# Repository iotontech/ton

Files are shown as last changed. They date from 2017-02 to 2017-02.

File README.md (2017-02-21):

Ton V1.2
========

The Ton V1.2 Board is a development and prototyping platform with Bluetooth Low Energy, Wi-Fi and IMU 9-axis,
based on the ARM Cortex-M4 32-bit microcontroller [STM32F405](http://www.st.com/web/en/catalog/mmc/SC1169/SS1577/LN1035/PF252144) developed by Brazilian startup [IOTON Technology](http://ioton.cc/).

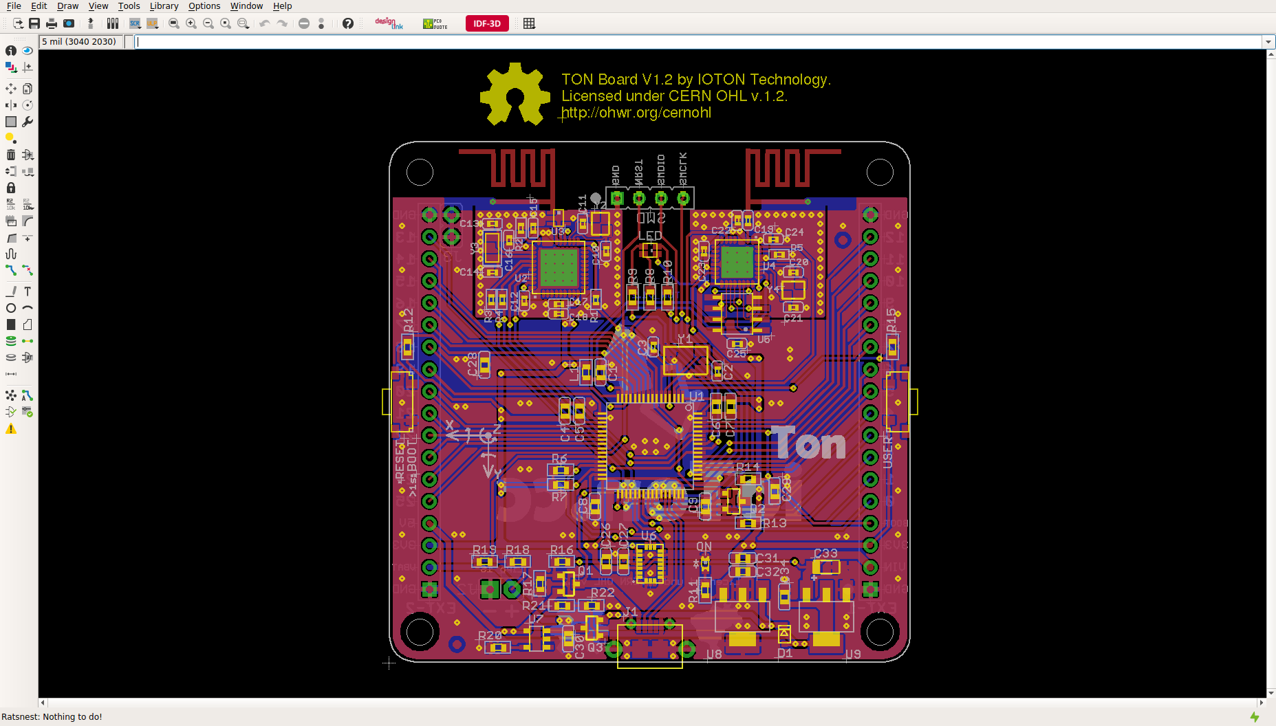
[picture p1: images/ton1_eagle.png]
ton1_eagle


# License

Copyright IOTON Technology 2017.

This documentation describes Open Hardware and is licensed under the CERN OHL v. 1.2.
You may redistribute and modify this documentation under the terms of the CERN OHL v.1.2. (http://ohwr.org/cernohl). This documentation is distributed WITHOUT ANY EXPRESS OR IMPLIED WARRANTY, INCLUDING OF MERCHANTABILITY, SATISFACTORY QUALITY AND FITNESS FOR A PARTICULAR PURPOSE. Please see the CERN OHL v.1.2 for applicable conditions.

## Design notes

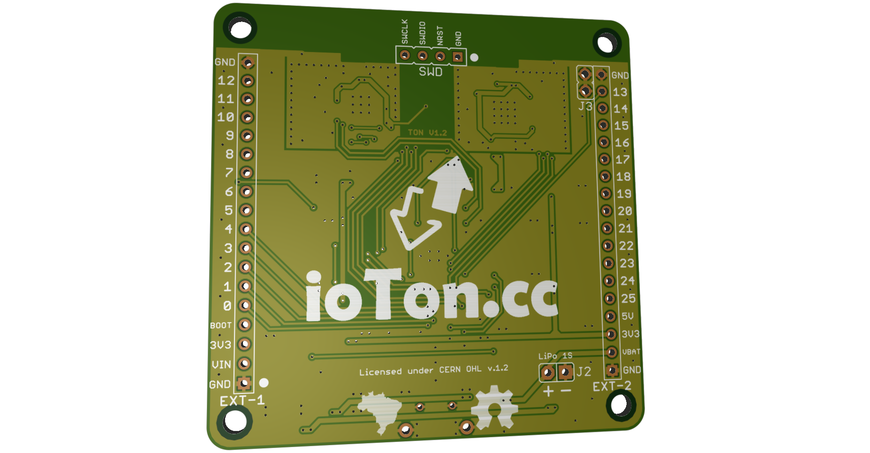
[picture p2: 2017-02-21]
images/ton1_bottom.png

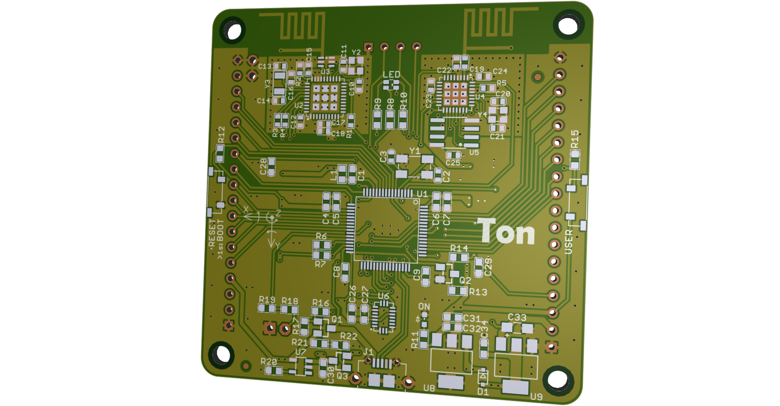
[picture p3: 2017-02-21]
images/ton1_top.png

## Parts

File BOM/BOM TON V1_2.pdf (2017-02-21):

Idn | Reference Designator | Item Type | Item Package | Item Desc | Qty | MFG Name | MFG P/N | Notes
1 | TON V1.2 | PCB | - | PCB, FR4, 1.6MM, BLUE SOLDERMASK, HASL, WHITE SILKSCREEN | 1 | | | TON_GERBERS_V1-2.ZIP
2 | C1, C5, C6, C26, C28, C31 | CERAMIC-CAP | 0603 | CAP CER 0.1UF 16V X7R 0603 10% | 6 | YAGEO | CC0603KRX7R7BB104
3 | C2, C3, C10, C11, C13, C14, C20, C21 | CERAMIC-CAP | 0402 | CAP CER 12PF 50V NP0 0402 5% | 8 | YAGEO | CC0402JRNPO9BN120
4 | C8, C9, C29 | CERAMIC-CAP | 0603 | CAP CER 2.2UF 6.3V X5R 0603 10% | 3 | YAGEO | CC0603KRX5R5BB225
5 | C4, C7, C27, C30, C32, C34 | CERAMIC-CAP | 0603 | CAP CER 1UF 6.3V X5R 0603 10% | 6 | YAGEO | CC0603KRX5R5BB105
6 | C12, C18, C25 | CERAMIC-CAP | 0402 | CAP CER 1UF 6.3V X5R 0402 10% | 3 | YAGEO | CC0402KRX5R5BB105
7 | C15, C17, C22, C24 | CERAMIC-CAP | 0402 | CAP CER 0.1UF 10V X5R 0402 10% | 4 | YAGEO | CC0402KRX5R6BB104
9 | C16, C23 | CERAMIC-CAP | 0402 | CAP CER 220PF 50V NP0 0402 5% | 2 | MURATA | GRM1555C1H221JA01
10 | C19 | CERAMIC-CAP | 0402 | CAP CER 5.6PF 50V NP0 0402 | 1 | MURATA | GRM1555C1H5R6CA01
11 | C33 | TANTALUM-CAP | 1206 | CAP TANT 10UF 1206 16V 10% | 1 | KEMET | T491A106K016AT
12 | D1 | DIODE | SOD-323 | DIODE SCHOTTKY 3.0A BAT60JFILM | 1 | STMICROELECTRONICS | BAT60JFILM
13 | EXT-1, EXT2 | HEADER-CONN | PTH-18 | CONNECTOR HEADER, FEMALE, 1X18, 2.54 PITCH | 2 | SULLINS CONNECTOR SOLUTIONS | PPTC181LFBN-RC
| | | | | | HARWIN | M20-7821842
14 | J1 | USB-CONN | SMD-5 | CONNECTOR USB MICRO AB RECEPTACLE | 1 | MOLEX | 47589-0001
15 | J2 | CONNECTOR | - | NOT PLACED | 0 | - | - | NOT PLACED
16 | J3 | HEADER-CONN | PTH-2 | CONNECTOR HEADER, MALE, 1X2, 2.54MM PITCH | 1 | 3M | 961102-6404-AR | CAN BE USED SINGLE ROW MALE 2.54MM BREAKABLE PIN HEADER CONNECTOR COMMON
| | | | | | FCI | 77311-818-02LF
17 | L1 | FERRITE-CHIP | 0603 | FERRITE CHIP 120 OHM 500MA 0603 | 1 | MURATA | BLM18AG121SN1D
| | | | | | TAIYO YUDEN | BK1608HS121-T
18 | LED | LED-RGB | 0606 | LED RGB 0606 | 1 | LITE-ON | LTST-C19HE1WT
19 | ON | LED | 0603 | LED GREEN 0603 | 1 | LITE-ON | LTST-C191KGKT
20 | Q1, Q3 | MOSFET | SSOT-3 | MOSFET FDN340P P-CHANNEL 20V 2A | 2 | FAIRCHILD SEMICONDUCTOR | FDN340P
21 | Q2 | MOSFET | SOT-23-3 | MOSFET BSS123 N-CHANNEL | 1 | FAIRCHILD SEMICONDUCTOR | BSS123
22 | R1, R3, R4 | RESISTOR-DISCRETE | 0402 | RES 0402 100 OHM 5% 1/16W | 3 | YAGEO | RC0402JR-07100RL
23 | R2 | RESISTOR-DISCRETE | 0402 | RES 0402 56.0K OHM 1% 1/16W | 1 | YAGEO | RC0402FR-0756KL
24 | R5 | RESISTOR-DISCRETE | 0402 | RES 0402 12.0K OHM 1% 1/16W | 1 | YAGEO | RC0402FR-0712KL
25 | R6, R7, R20 | RESISTOR-DISCRETE | 0603 | RES 0603 3.3K OHM 5% 1/10W | 3 | YAGEO | RC0603JR-073K3L
26 | R8, R11 | RESISTOR-DISCRETE | 0603 | RES 0603 200 OHM 5% 1/10W | 2 | YAGEO | RC0603JR-07200RL
27 | R9, R10 | RESISTOR-DISCRETE | 0603 | RES 0603 100 OHM 5% 1/10W | 2 | YAGEO | RC0603JR-07100RL
28 | R12, R14, R15, R19 | RESISTOR-DISCRETE | 0603 | RES 0603 47K OHM 5% 1/10W | 4 | YAGEO | RC0603JR-0747KL
29 | R13 | RESISTOR-DISCRETE | 0603 | RES 0603 470K OHM 5% 1/10W | 1 | YAGEO | RC0603JR-07470KL
30 | R16, R17, R21, R22 | RESISTOR-DISCRETE | 0603 | RES 0603 100K OHM 5% 1/10W | 4 | YAGEO | RC0603JR-07100KL
31 | R18 | RESISTOR-DISCRETE | 0603 | RES 0603 22K OHM 5% 1/10W | 1 | YAGEO | RC0603JR-0722KL
32 | RESET, USER | TACTILE-SWITCH | SMD-4 | TACTILE SWITCH SPST-NO RIGHT ANGLE | 2 | E-SWITCH | TL3330AF130QG
33 | SWD | CONNECTOR | - | NOT PLACED | 0 | - | - | NOT PLACED
34 | U1 | IC | LQFP-64 | IC MCU STM32F405RGT6 | 1 | STMICROELECTRONICS | STM32F405RGT6
35 | U2 | IC | VFQFN-40 | IC BLUETOOTH CC2541F256 | 1 | TEXAS INTRUMENTS | CC2541F256RHA
36 | U3 | MISCELLANEOUS | 0805 | MATCHED BALUN 2.45 GHZ | 1 | JOHANSON TECHNOLOGY | 2450BM15A0002
37 | U4 | IC | QFN-32 | IC WI-FI ESP8266EX | 1 | ESPRESSIF | ESP8266EX
38 | U5 | IC | SOIC-8 | IC FLASH 16MBIT QUAD SPI | 1 | WINBOND ELECTRONICS | W25Q16DVSNIG
39 | U6 | IC | LGA-20 | IC IMU 9-AXIS BMX055 | 1 | BOSCH SENSORTEC | BMX055
40 | U7 | IC | SOT-23-5 | IC CONTROLLER LI-ION MCP73831 | 1 | MICROCHIP TECHNOLOGY | MCP73831T-2ACI/OT
41 | U8 | IC | SOT-223-3 | IC LDO VOLTAGE REGULATOR 3.3V | 1 | DIODES INCORPORATED | AP7361C-33E-13
42 | U9 | IC | SOT-223-3 | IC LDO VOLTAGE REGULATOR 5.0V | 1 | DIODES INCORPORATED | AZ1117EH-5.0
43 | Y1 | CRYSTAL | SMD-4 | CRYSTAL ABM3B 8 MHZ | 1 | ABRACON | ABM3B-8.000MHZ-10-1UT
44 | Y2 | CRYSTAL | SMD-4 | CRYSTAL FA-20H 32 MHZ | 1 | EPSON | FA-20H 32.0000MF20X-K3
45 | Y3 | CRYSTAL | SMD-2 | CRYSTAL 32.768 KHZ | 1 | ECS | ECS-.327-12.5-34B-TR
46 | Y4 | CRYSTAL | SMD-4 | CRYSTAL FA-20H 26 MHZ | 1 | EPSON | FA-20H 26.0000MF10Z-AC3

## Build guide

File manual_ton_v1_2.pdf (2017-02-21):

Manual – Ton V1.2

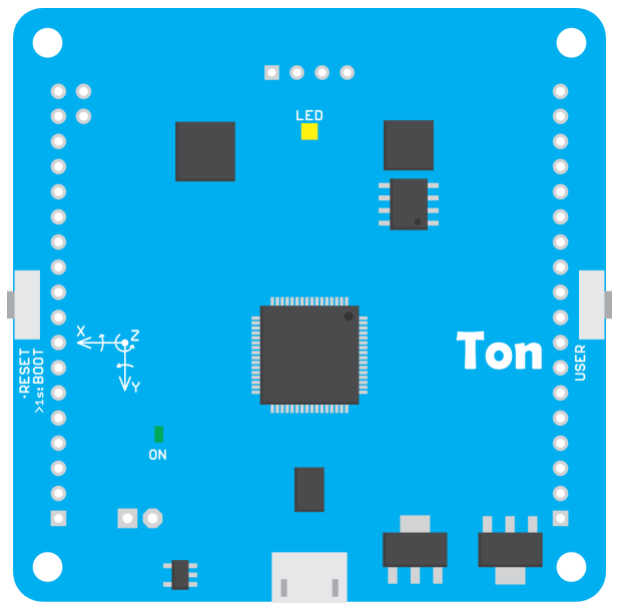
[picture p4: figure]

IOTON TECHNOLOGY – Uberlândia, abril de 2016
Site: ioton.cc (http://ioton.cc/?utm_source=google&utm_medium=referral&utm_campaign=documentacao) | E-mail: contato@ioton.cc

# TON V1.2

IOTON TECHNOLOGY | 1

# 1. Visão Geral

Ton é uma plataforma de desenvolvimento e prototipação baseada no microcontrolador ARM Cortex-M4 32-bit STM32F405. (http://www.st.com/web/en/catalog/mmc/SC1169/SS1577/LN1035/PF252144) Ele já integra uma unidade de medição inercial com 9 eixos, USB host/device, Bluetooth e Wi-Fi para você implementar suas ideias em eletrônica, robótica e IoT de uma forma simples, porém muito poderosa com um processador de 210 DMIPS (210 milhões de instruções por segundo). São 26 pinos de entradas/saídas, sendo até 12 saídas PWM e até 12 entradas analógicas. Pode ser alimentado pelo conector USB, pelo conector header ou ainda por bateria de uma célula de Li-Po (com carregador integrado). O seu header principal também permite a conexão com os seguintes periféricos: 4 UART, 2 saídas DAC, 1 i²C, 1 SPI e 1 SDIO.

A programação do Ton é realizada a partir do editor de texto Atom (https://atom.io/) e do package da IOTON que permite a utilização de todos estes recursos com uma abordagem bem prática e intuitiva. Na etapa inicial de criação do projeto, o usuário define as funções dos pinos de entradas/saídas, com isso, é gerado automaticamente todas as configurações e funções de acesso para os respectivos periféricos. Mesmo com poucas noções de programação é possível aproveitar todos os recursos do Ton devido à abstração de alto nível da API desenvolvida em linguagem C/C++ e com o uso de bibliotecas do mbed SDK. (https://github.com/mbedmicro/mbed)

IOTON TECHNOLOGY | 2

# 2. Especificações Técnicas

Microcontrolador | STM32F405RGT6
Memória Flash | 1024 KB
SRAM | 192 KB
Clock | 168 MHz (210 DMIPS)
Tensão de operação | 3,3 V (1)
Tensão de entrada (VIN) | 6 a 12 V
Corrente DC por pino | 8 mA
Corrente DC dos pinos 3V3 e 5V | 500 mA
Corrente DC do carregador Lipo 1S | 300 mA
Bluetooth Low Energy | CC2541
Botões | Reset e Usuário
IMU 9DOF | BMX055
LEDs de usuário | RGB (com PWM)
USB 2.0 full-speed | Host/device
Wi-Fi | ESP8266
Total de pinos I/O | 26 (todos com interrupção)
Saídas PWM | até 12
Entradas analógicas 12-bit | até 12
UART | 4
Saídas DAC 12-bit | 2
I²C | 1
SPI | 1
SDIO (sd card) | 1
Dimensões | 60x60x13mm
1. Os pinos de I/O são 5 V tolerantes, exceto os pinos 20 e 21

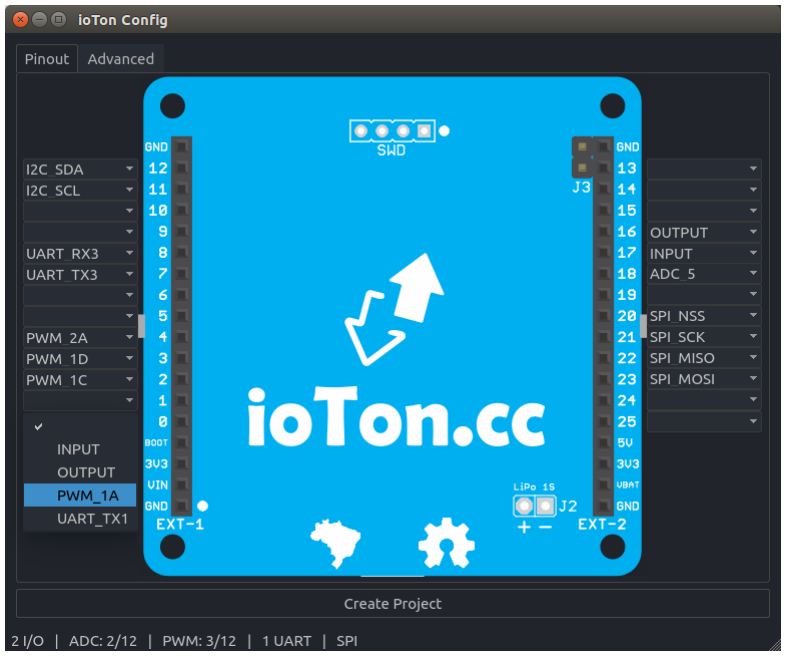
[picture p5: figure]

IOTON TECHNOLOGY | 3

# 3. Detalhes

Programando

Para programar o Ton é utilizado o editor de texto Atom em conjunto com um package que permite: configurar o projeto, compilar o código, enviar ao dispositivo e comunicar via USB (escrita/leitura). Com isso, tem-se um ambiente de desenvolvimento enxuto, de fácil utilização e com todas as funcionalidades deste ótimo editor.

A tela de configuração do projeto permite ao usuário selecionar a função de cada pino:

De acordo com esta configuração são geradas (automaticamente) todas as funções de configuração do microcontrolador e funções de acesso aos respectivos periféricos selecionados (UART, ADC, DAC, SPI, etc). Isso possibilita uma forma prática de usar todo o poder do microcontrolador ARM 32bit de 168 MHZ.

IOTON TECHNOLOGY | 4

Alimentação

O Ton pode ser alimentado pelo conector micro USB, externamente pelos conectores EXT-1 e EXT-2 (pinos GND, 3V3 ou VIN), ou ainda por uma bateria Li-Po de uma célula.

Observações quanto aos pinos de alimentação dos conectores EXT-1 e EXT-2:

- GND: pinos de Terra.
- 3V3: saída regulada de até 500 mA.
- VBAT: entrada para bateria Li-Po 1S (3,7V) ou pode ser usada com saída da tensão da bateria, se esta estiver conectada ao J2.
- VIN: entrada de alimentação entre 6 e 12V.
- 5V: saída regulada de até 500 mA para os casos em que o Ton esteja alimentado pela USB ou pelo VIN.

Conectores

Os conectores EXT-1 e EXT-2 possuem 26 pinos de entrada e saída, eles são numerados de 0 a 25, cada um destes pinos tem várias funções diferentes e devem ser configurados de acordo com sua utilização por meio da tela de configuração do ambiente de programação.

Com um hardware externo (ST-LINK ou similares) é possível debugar o código através do conector SWD.

Todos os pinos de I/O têm capacidade para configurar interrupções externas. Com exceção dos pinos 20 e 21, todos são 5 V tolerantes, porém quando configurado como entrada analógica a tensão de 3,3 V não deve ser ultrapassada.

IOTON TECHNOLOGY | 5

Mapa dos pinos

A seguir são apresentadas as funções de cada pino:

I/O

Funções
ADC | PWM | UART | DAC | I2C | SPI | SDIO
0 | 1A | TX1
1 | 1B | RX1
2 | 1C | D0
3 | 1D | D1
4 | 2A
5 | TX2 | D2
6 | RX2 | D3
7 | TX3 | CK
8 | RX3 | CMD
9 | 2B
10 | 3A
11 | 4A | SCL
12 | 4B | SDA
13 | 3B
14 | ✓
15 | ✓
16 | ✓
17 | ✓
18 | ✓ | 5A | TX4
19 | ✓ | 5B | RX4
20 | ✓ | ✓ | NSS
21 | ✓ | ✓ | SCK
22 | ✓ | MISO
23 | ✓ | MOSI
24 | ✓
25 | ✓
*Todos os pinos podem ser configurados como entrada/saída digitais

Observações:

- ADC: a resolução do conversor é de 12-bit (4096 valores diferentes). Neste modo a tensão do pino não deve exceder 3,3 V.
- PWM: são 12 pinos de PWM com cinco grupos diferentes (alguns grupos possuem mais de um canal e são diferenciados pelas letras A, B, C e D). Cada grupo pode ser configurado com uma frequência diferente.

IOTON TECHNOLOGY | 6
- UART: cada uma das quatro UART são configuradas separadas e podem ter baudrates diferentes.
- DAC: saídas analógicas de 12-bit, resistência de carga mínima = 5 kΩ.
- I²C e SPI: barramentos seriais para comunicação com uma infinidade de circuitos integrados.
- SDIO: interface para cartões de multimídia (SD Card e MMC).

IMU 9 DOF

A Unidade de Medição Inercial (Inertial Measurement Unit – IMU) utiliza o circuito integrado BMX055 (http://www.bosch-sensortec.com/bst/products/all_products/bmx055) com acelerômetro, giroscópio e magnetômetro de três eixos cada, totalizando nove graus de liberdade (9 DOF).

A partir desta unidade são fornecidos dados que possibilitam obter orientação, posicionamento e velocidade do dispositivo.

Comunicação

O Ton já vem equipado com uma série de periféricos que permitem se conectar com computadores, outro Ton, demais microcontroladores, smartphones, entre outros dispositivos. Suas principais formas de conexão com o mundo tecnológico são: USB, Bluetooth e Wi-Fi.

- USB: é através do conector USB micro que o Ton é programado, ele também pode ser utilizado para enviar e receber dados de um computador ou smartphone.
- Bluetooth (chipset CC2541): (http://www.ti.com/product/CC2541) o módulo Bluetooth integrado ao Ton permite a comunicação sem fio com computadores e smartphones.
- Wi-Fi (chipset ESP8266): (http://espressif.com/en/products/esp8266/) projetos na Internet de maneira simples e rápida para entrar no mundo IoT.

Os conectores EXT-1 e EXT-2 ainda possui outras interfaces (UART, I²C e SPI) para deixar seu projeto ainda mais conectado.

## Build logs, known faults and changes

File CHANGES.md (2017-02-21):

Here we are compiling a community changelog.

If you come up with a modification of our designs, please share it with the community, log your changes below, and upload the files to our GitHub repository.

#Format

**Your name**  
*Date*  
Description of modification  

#Example

* older entry

* **Kleber Lima da Silva**   
*12/31/2032*  
I used the original board design (electronics), but changed the BLE chipset. I created a pull request on GitHub with the modified files.

* newer entry

#Changelog

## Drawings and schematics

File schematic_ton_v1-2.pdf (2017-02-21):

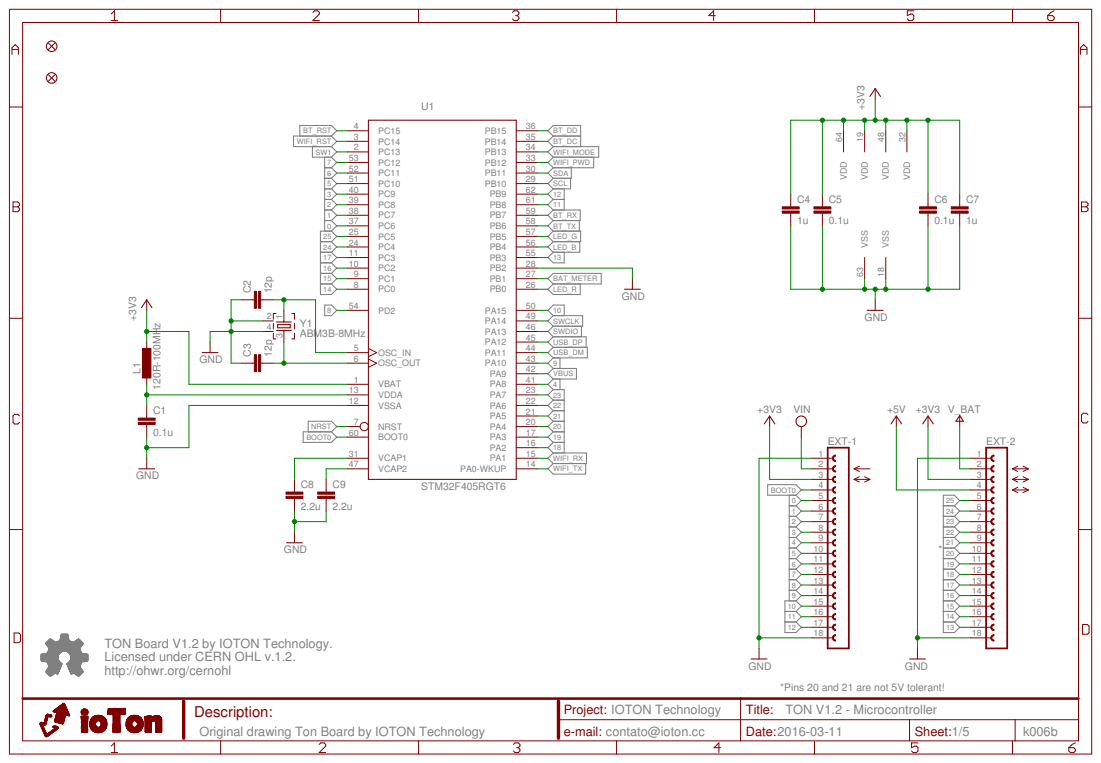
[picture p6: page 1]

TON Board V1.2 by IOTON Technology. Licensed under CERN OHL v.1.2. http://ohwr.org/cernohl

GND
*Pins 20 and 21 are not 5V tolerant!

Description: Original drawing Ton Board by IOTON Technology | Project: IOTON Technology | Title: TON V1.2 - Microcontroller

e-mail: contato@ioton.cc | Date: 2016-03-11 | Sheet: 1/5 | k006b

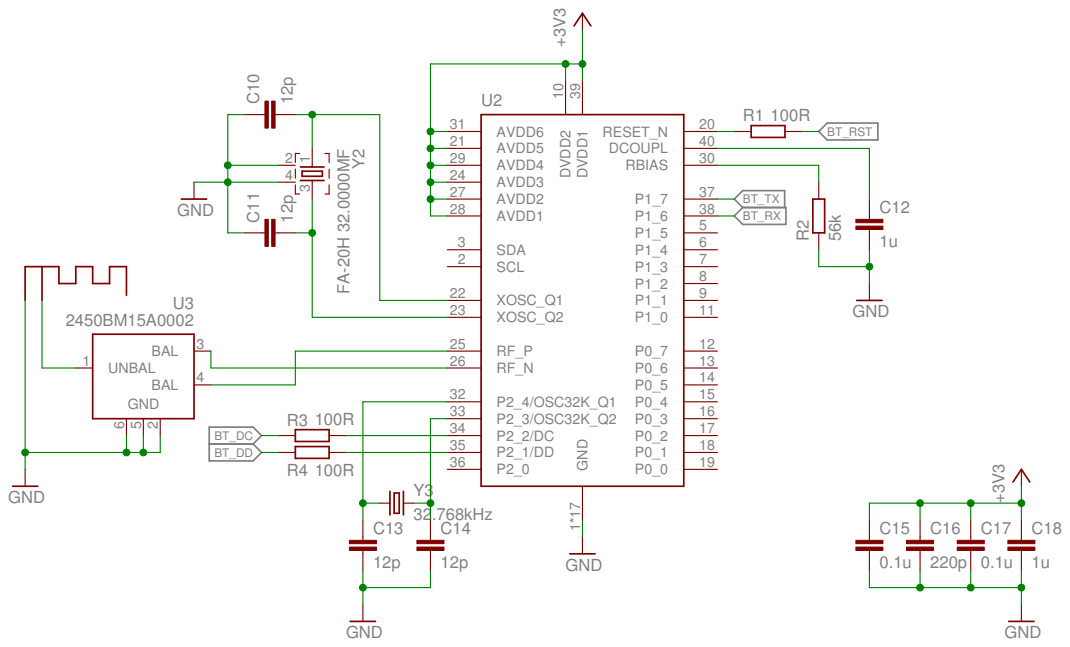
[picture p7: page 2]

Description: Original drawing Ton Board by IOTON Technology | Project: IOTON Technology | Title: TON V1.2 - Bluetooth Low Energy

e-mail: contato@ioton.cc | Date: 2016-03-11 | Sheet: 2/5 | k006b

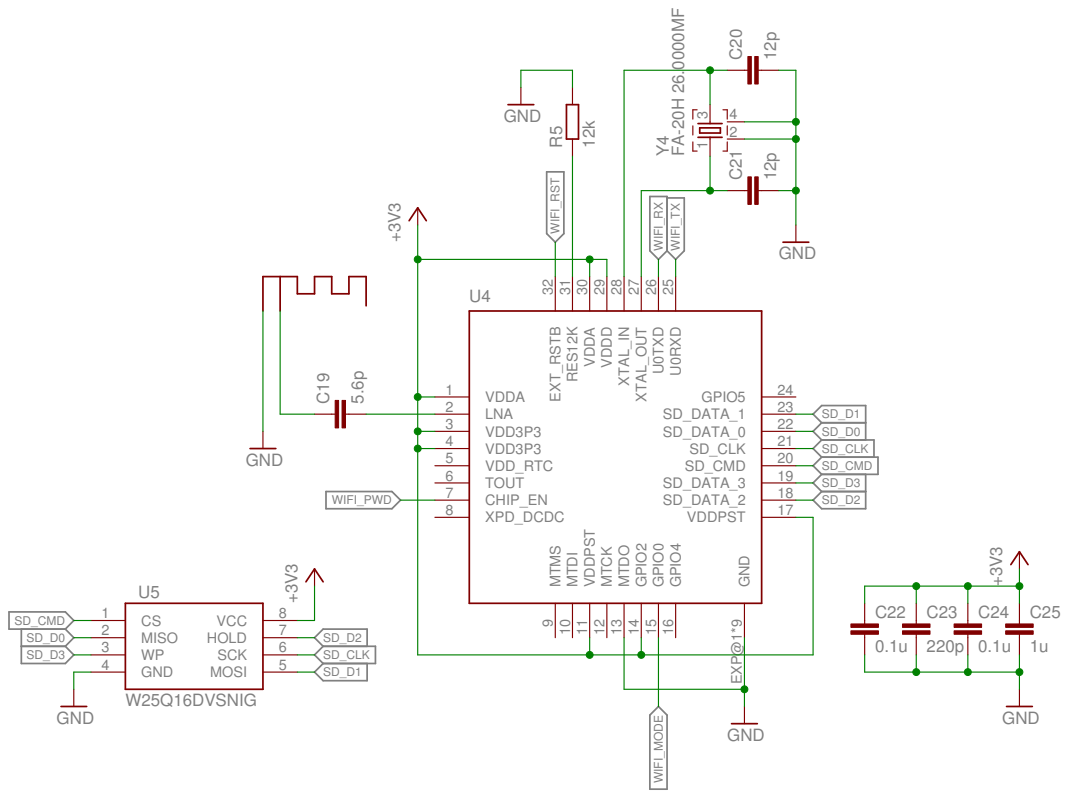
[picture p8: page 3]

Description: Original drawing Ton Board by IOTON Technology | Project: IOTON Technology | Title: TON V1.2 - Wi-Fi

e-mail: contato@ioton.cc | Date: 2016-03-11 | Sheet: 3/5 | k006b

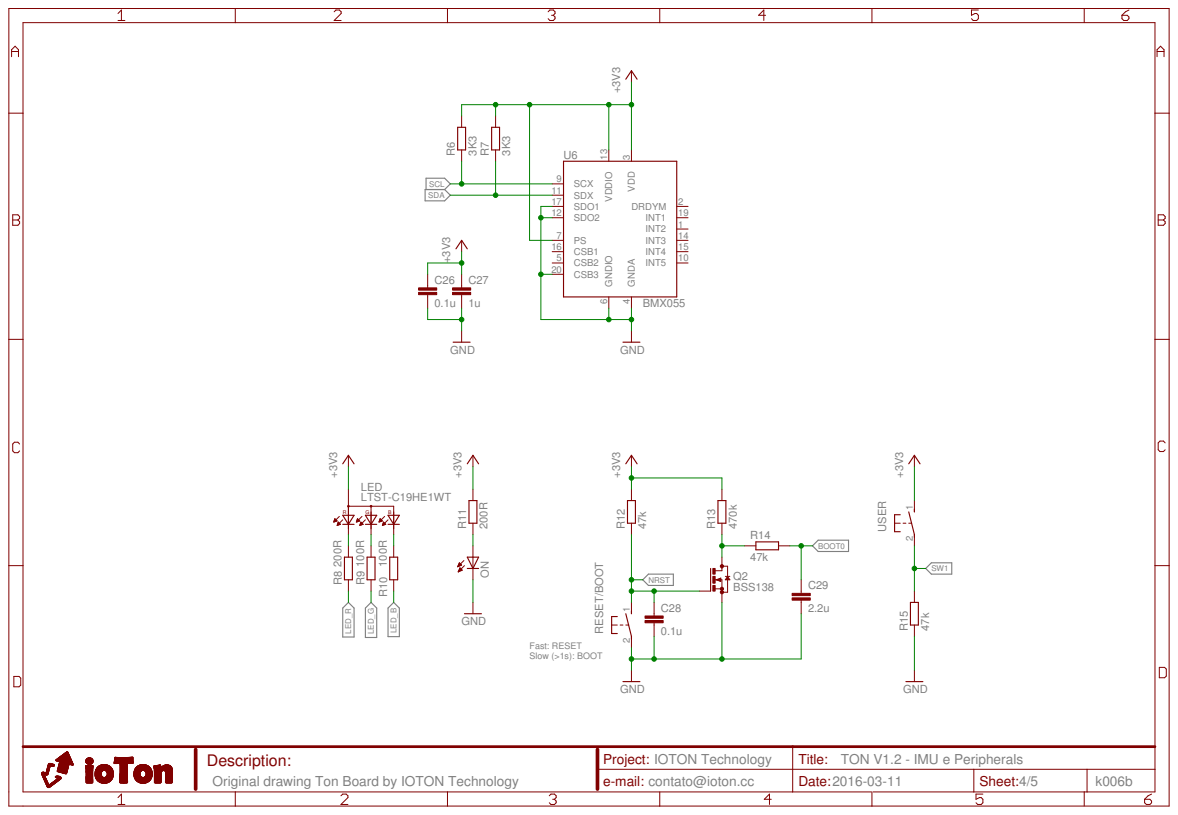
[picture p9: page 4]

Fast: RESET Slow (>1s): BOOT

Description: Original drawing Ton Board by IOTON Technology | Project: IOTON Technology | Title: TON V1.2 - IMU e Peripherals

e-mail: contato@ioton.cc | Date: 2016-03-11 | Sheet: 4/5 | k006b

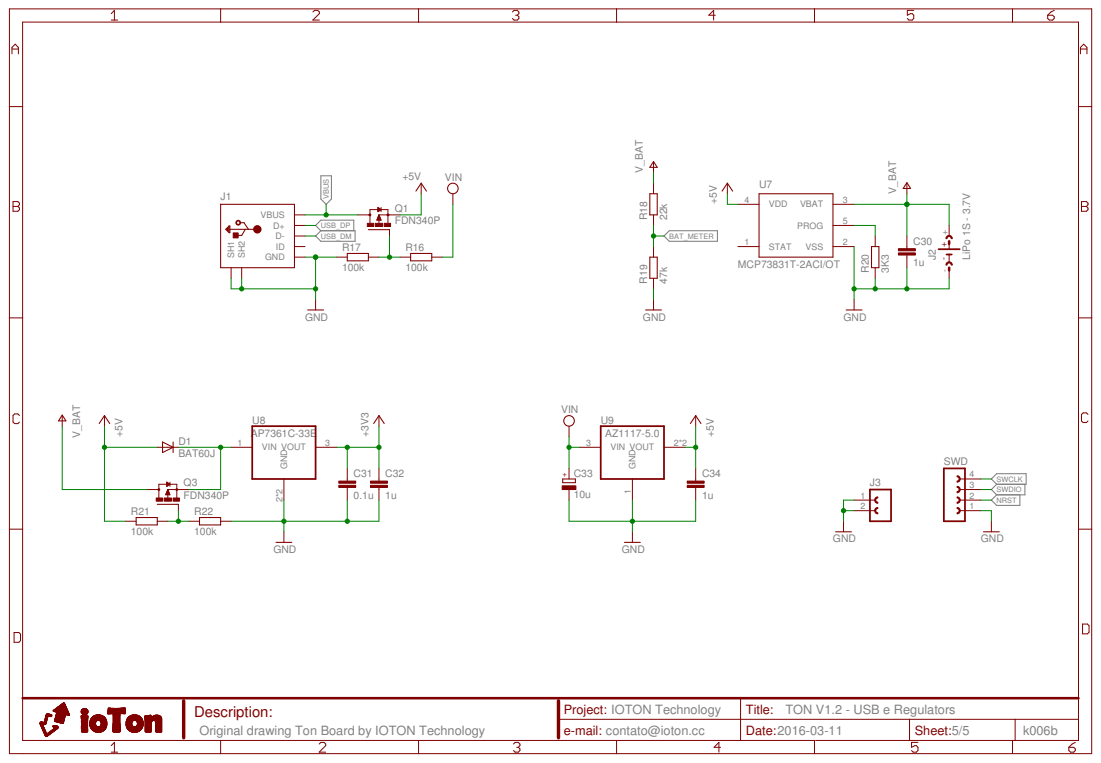
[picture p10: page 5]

Description: Original drawing Ton Board by IOTON Technology | Project: IOTON Technology | Title: TON V1.2 - USB e Regulators

e-mail: contato@ioton.cc | Date: 2016-03-11 | Sheet: 5/5 | k006b

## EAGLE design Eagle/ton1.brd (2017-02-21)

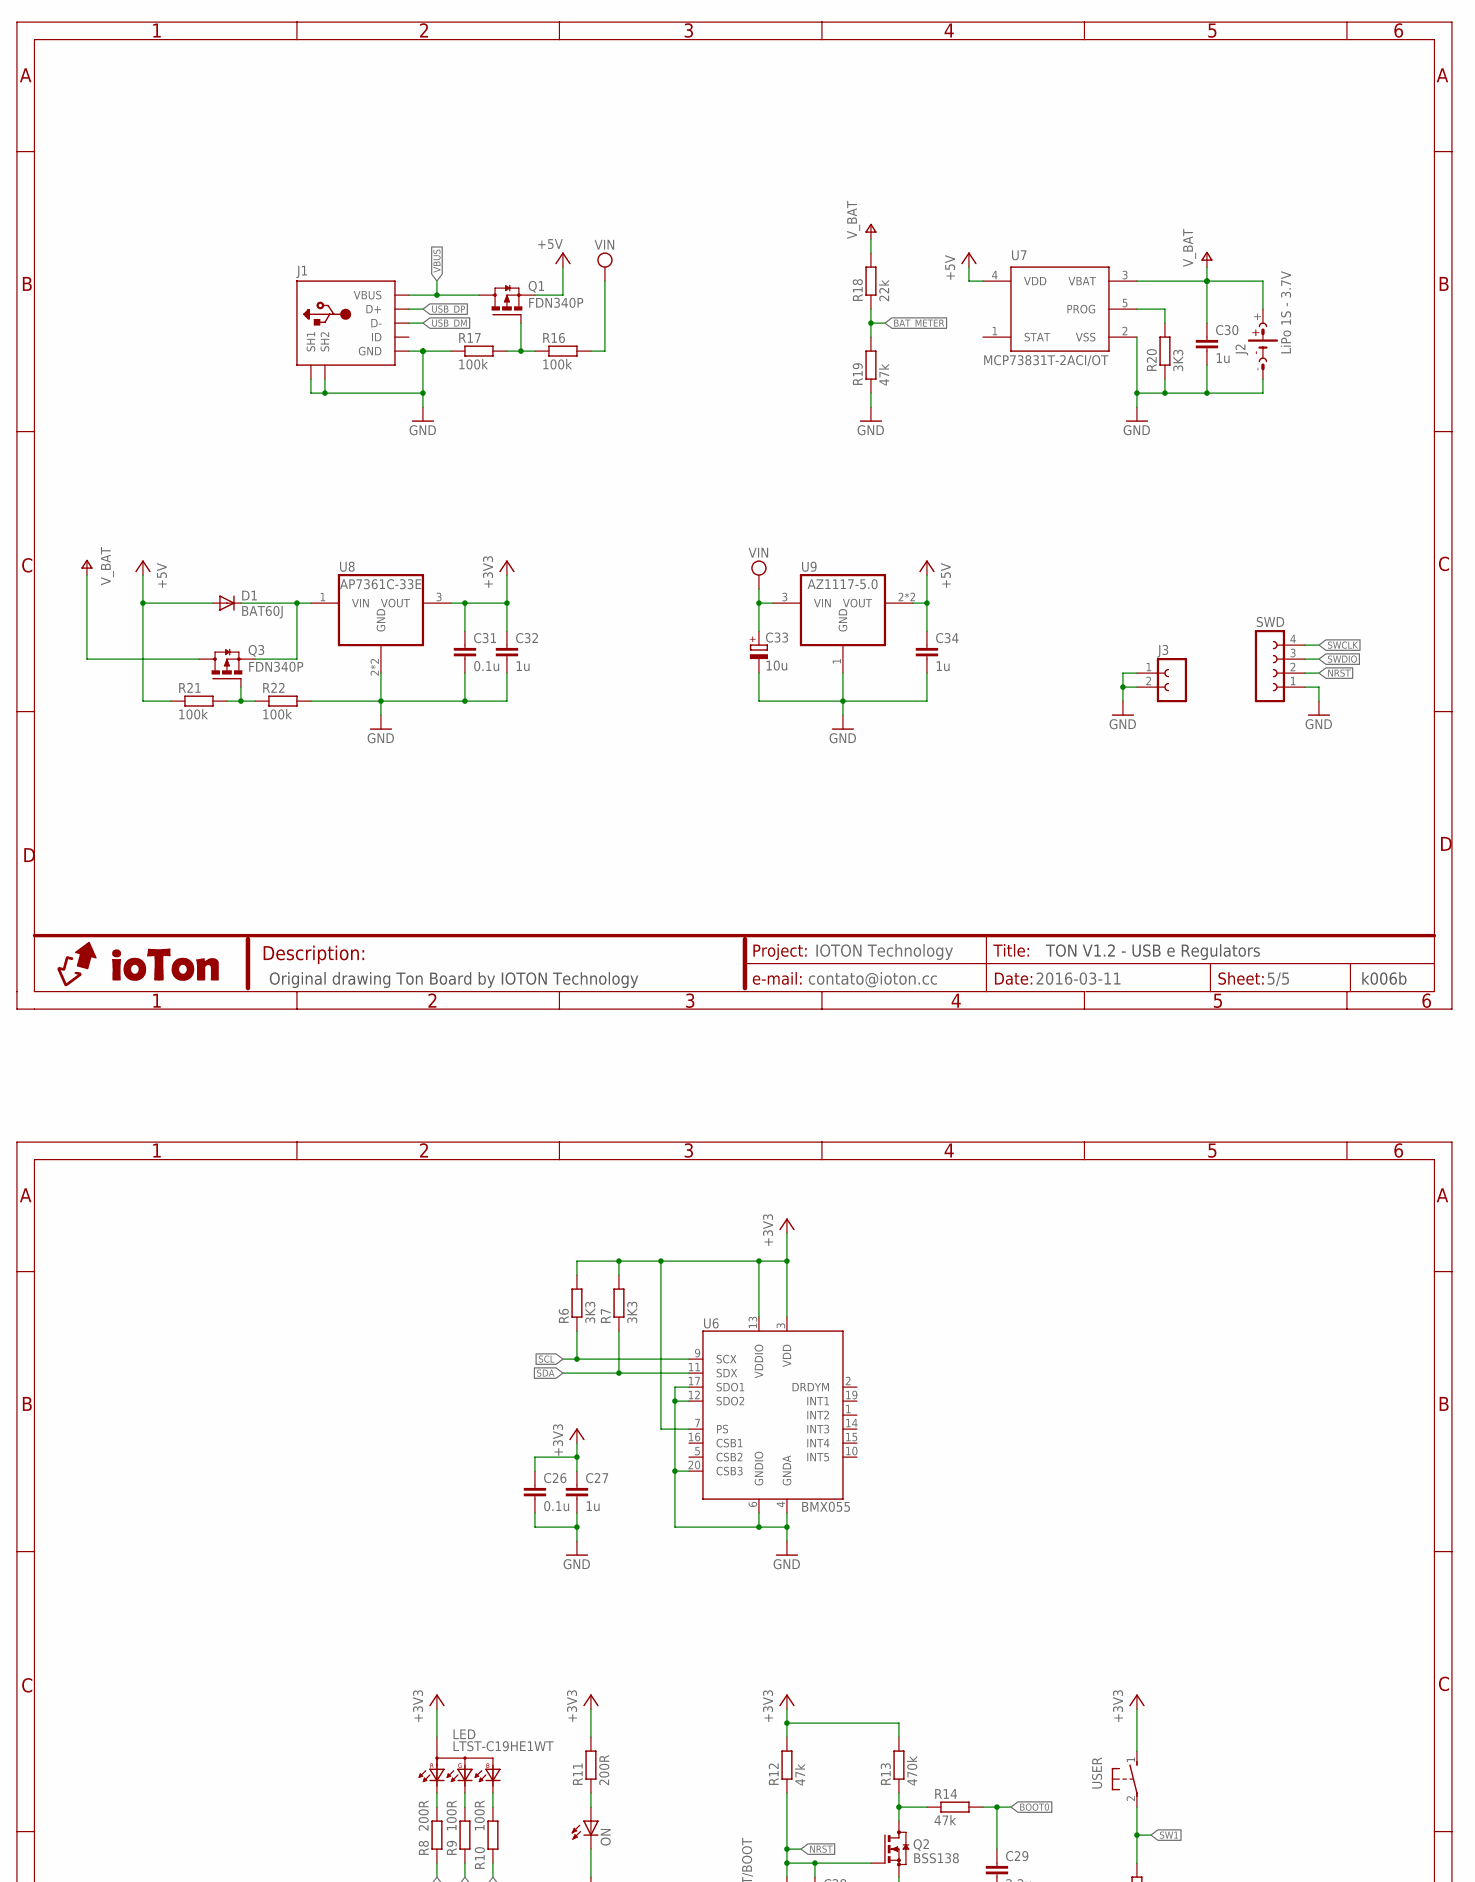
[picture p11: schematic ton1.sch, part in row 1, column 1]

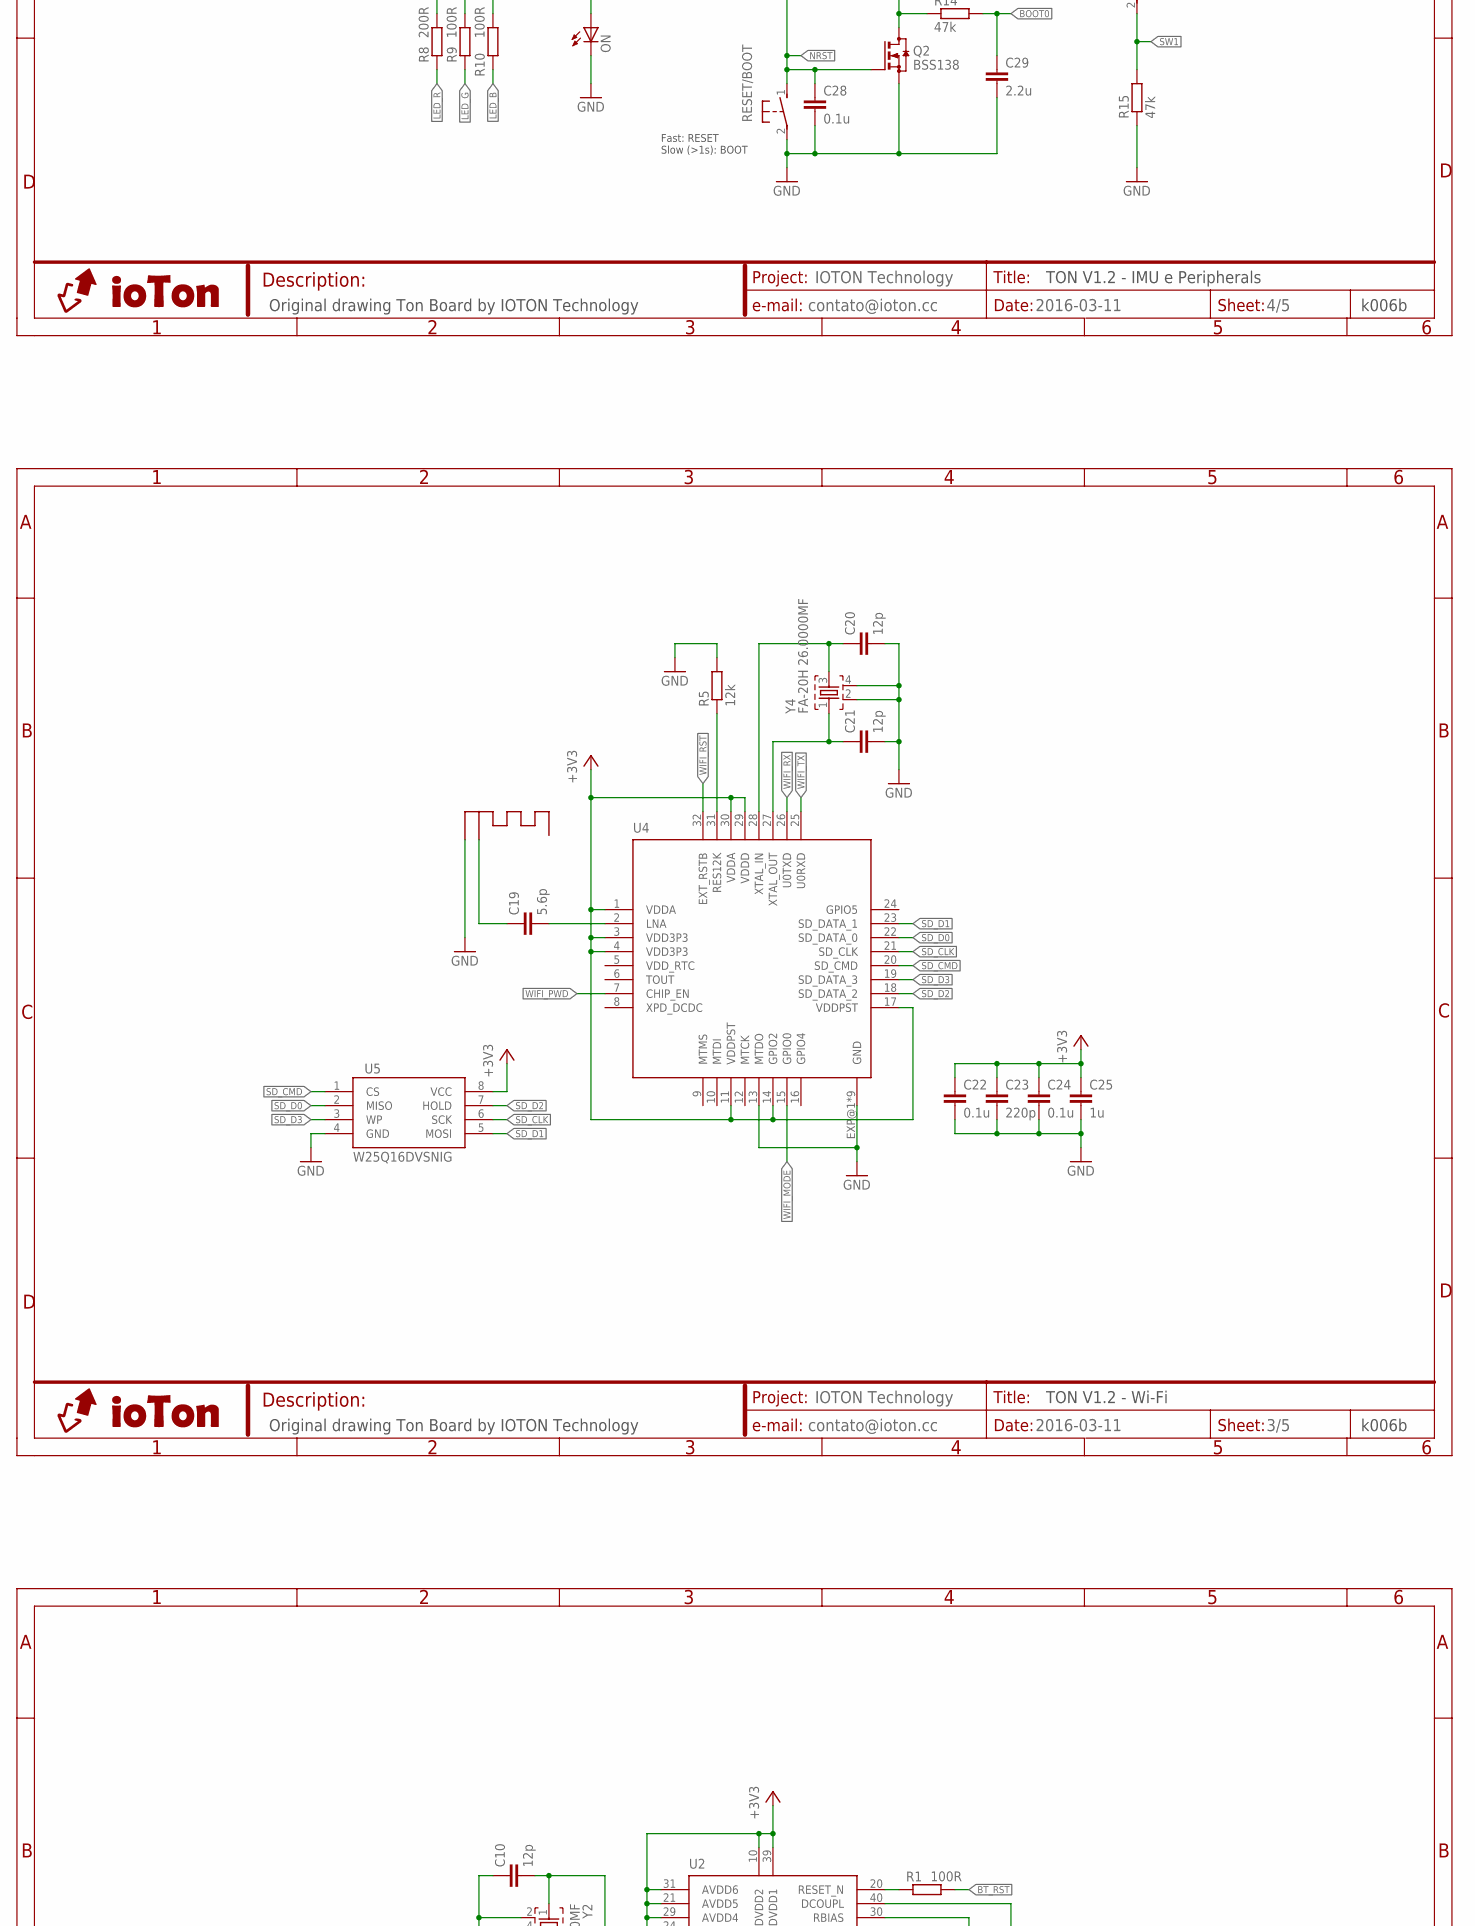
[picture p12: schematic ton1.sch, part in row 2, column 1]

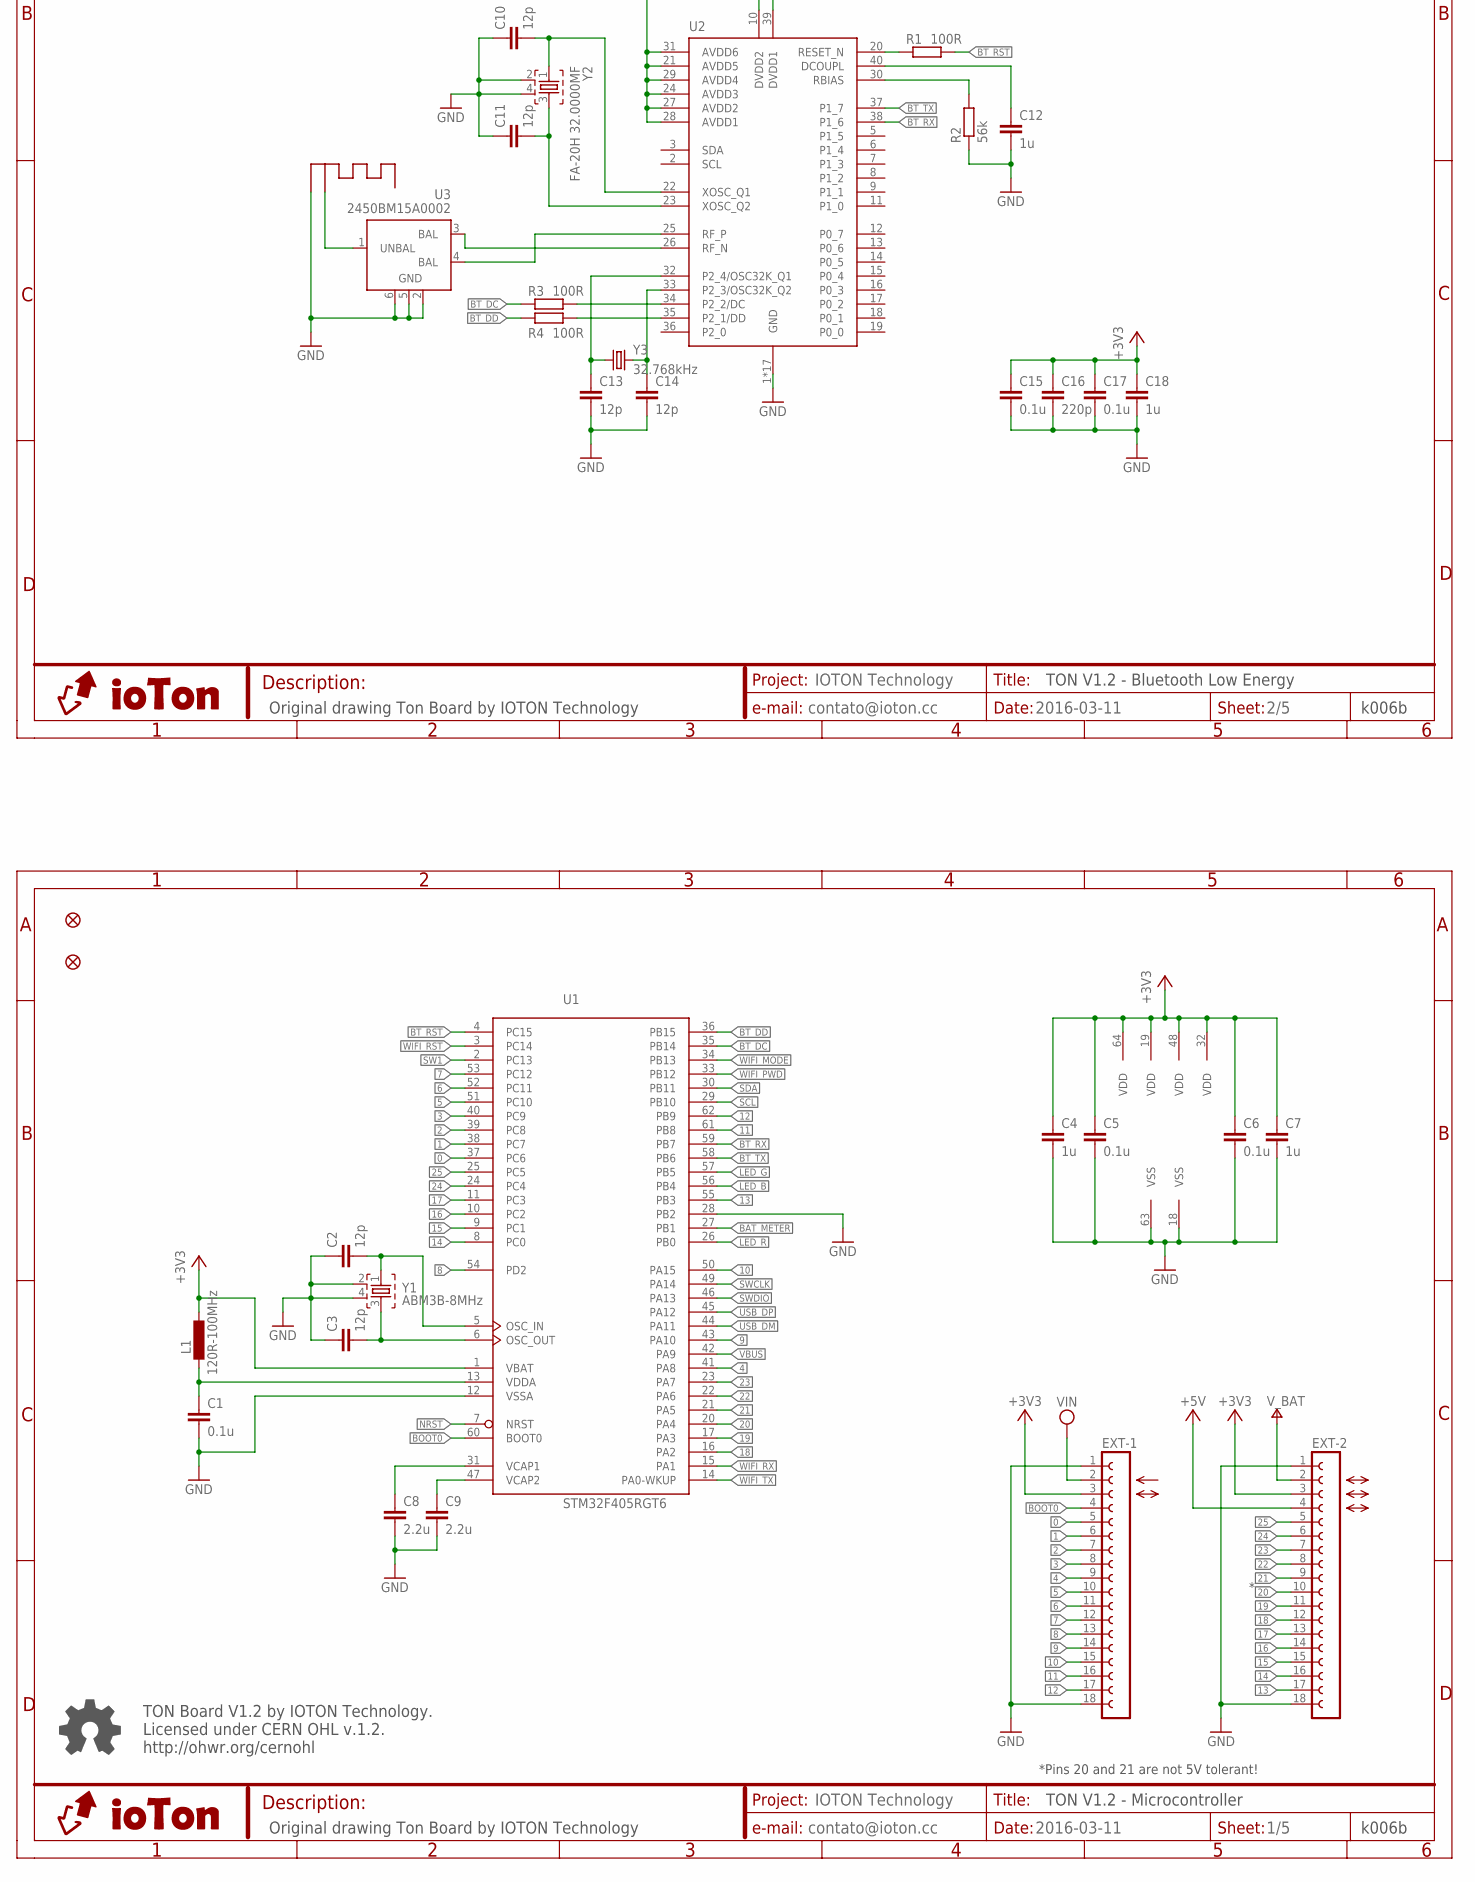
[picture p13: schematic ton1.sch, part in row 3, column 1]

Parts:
C1, C5, C6, C26, C28, C31: 0.1u; C0603
C2, C3, C10, C11, C13, C14, C20, C21: 12p; C0402
C4, C7, C27, C30, C32, C34: 1u; C0603
C8, C9, C29: 2.2u; C0603
C12, C18, C25: 1u; C0402
C15, C17, C22, C24: 0.1u; C0402
C16, C23: 220p; C0402
C19: 5.6p; C0402
C33: 10u; SMC_A
D1: BAT60J; SOD323-R
EXT-1, EXT-2: 1_18
J1: USBR; 0475890001
J2: LiPo 1S - 3.7V; BATTERY
J3: 1_2
JP1, JP2: FIDUCIAL1X2; FIDUCIAL-1X2
L1: 120R-100MHz; LR0603
LED: LTST-C19HE1WT; 0606
ON: LEDCHIPLED_0603; CHIPLED_0603
Q1, Q3: FDN340P; SUPER-SOT3
Q2: BSS138; SOT23
R1, R3, R4: 100R; R0402
R2: 56k; R0402
R5: 12k; R0402
R6, R7, R20: 3K3; R0603
R8, R11: 200R; R0603
R9, R10: 100R; R0603
R12, R14, R15, R19: 47k; R0603
R13: 470k; R0603
R16, R17, R21, R22: 100k; R0603
R18: 22k; R0603
RESET/BOOT: SWITCH; SW_TL-3330
SWD: FE04-11; CON4-1_1
U1: STM32F405RGT6; LQFP64
U2: CC2541; QFN40-6X6
U3: 2450BM15A0002
U4: ESP8266O; QFN32-5X5-O
U5: W25Q16DVSNIG; SO08
U6: BMX055; LGA20-4.5X3
U7: MCP73831T-2ACI/OT; SOT23-5L
U8: AP7361C-33E; SOT223
U9: AZ1117-5.0; SOT223
U$1: ANT_PCBR; ANT_MIFA_R
U$2: ANT_PCBL; ANT_MIFA_L
USER: SWITCH; SW_TL-3330
Y1: ABM3B-8MHz; ABM3B
Y2: FA-20H 32.0000MF; FA-20H
Y3: 32.768kHz; 3.2X1.5
Y4: FA-20H 26.0000MF; FA-20H

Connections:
0: EXT-1.5, U1.37 (PC6)
1: EXT-1.6, U1.38 (PC7)
2: EXT-1.7, U1.39 (PC8)
3: EXT-1.8, U1.40 (PC9)
4: EXT-1.9, U1.41 (PA8)
5: EXT-1.10, U1.51 (PC10)
6: EXT-1.11, U1.52 (PC11)
7: EXT-1.12, U1.53 (PC12)
8: EXT-1.13, U1.54 (PD2)
9: EXT-1.14, U1.43 (PA10)
10: EXT-1.15, U1.50 (PA15)
11: EXT-1.16, U1.61 (PB8)
12: EXT-1.17, U1.62 (PB9)
13: EXT-2.17, U1.55 (PB3)
14: EXT-2.16, U1.8 (PC0)
15: EXT-2.15, U1.9 (PC1)
16: EXT-2.14, U1.10 (PC2)
17: EXT-2.13, U1.11 (PC3)
18: EXT-2.12, U1.16 (PA2)
19: EXT-2.11, U1.17 (PA3)
20: EXT-2.10, U1.20 (PA4)
21: EXT-2.9, U1.21 (PA5)
22: EXT-2.8, U1.22 (PA6)
23: EXT-2.7, U1.23 (PA7)
24: EXT-2.6, U1.24 (PC4)
25: EXT-2.5, U1.25 (PC5)
+3V3: C4.1, C5.1, C6.1, C7.1, C15.1, C16.1, C17.1, C18.1, C22.1, C23.1, C24.1, C25.1, C26.1, C27.1, C31.1, C32.1, EXT-1.3, EXT-2.3, L1.2, LED.4 (A), R6.2, R7.2, R11.2, R12.2, R13.2, U1.1 (VBAT), U1.19 (VDD), U1.32 (VDD), U1.48 (VDD), U1.64 (VDD), U2.10 (DVDD2), U2.21 (AVDD5), U2.24 (AVDD3), U2.27 (AVDD2), U2.28 (AVDD1), U2.29 (AVDD4), U2.31 (AVDD6), U2.39 (DVDD1), U4.1 (VDDA), U4.3 (VDD3P3), U4.4 (VDD3P3), U4.11 (VDDPST), U4.14 (GPIO2), U4.17 (VDDPST), U4.29 (VDDD), U4.30 (VDDA), U5.8 (VCC), U6.3 (VDD), U6.7 (PS), U6.13 (VDDIO), U8.3 (VOUT), USER.1
+5V: C34.1, D1.A, EXT-2.4, Q1.2 (S), R21.1, U7.4 (VDD), U9.2 (VOUT), U9.4 (VOUT)
BAT_METER: R18.1, R19.2, U1.27 (PB1)
BOOT0: C29.1, EXT-1.4, R14.2, U1.60 (BOOT0)
BT_ANT: U3.1 (UNBAL), U$2.ANT
BT_DC: R3.1, U1.35 (PB14)
BT_DD: R4.1, U1.36 (PB15)
BT_RST: R1.2, U1.4 (PC15)
BT_RX: U1.59 (PB7), U2.38 (P1_6)
BT_TX: U1.58 (PB6), U2.37 (P1_7)
GND: C1.2, C2.1, C3.1, C4.2, C5.2, C6.2, C7.2, C8.2, C9.2, C10.1, C11.1, C12.2, C13.2, C14.2, C15.2, C16.2, C17.2, C18.2, C20.2, C21.2, C22.2, C23.2, C24.2, C25.2, C26.2, C27.2, C28.2, C29.2, C30.2, C31.2, C32.2, C33.-, C34.2, EXT-1.1, EXT-1.18, EXT-2.1, EXT-2.18, J1.5 (GND), J1.SH1, J1.SH2 (SH1), J1.SH3 (SH2), J1.SH4 (SH2), J1.SH5 (SH1), J1.SH6 (SH2), J2.-, J3.1, J3.2, ON.C, Q2.2 (S), R2.1, R5.2, R15.1, R17.1, R19.1, R20.1, R22.2, RESET/BOOT.2, SWD.1, U1.12 (VSSA), U1.18 (VSS), U1.28 (PB2), U1.63 (VSS), U2.1 (GND), U2.EXP@1 (GND), U2.EXP@2 (GND), U2.EXP@3 (GND), U2.EXP@4 (GND), U2.EXP@5 (GND), U2.EXP@6 (GND), U2.EXP@7 (GND), U2.EXP@8 (GND), U2.EXP@9 (GND), U2.EXP@10 (GND), U2.EXP@11 (GND), U2.EXP@12 (GND), U2.EXP@13 (GND), U2.EXP@14 (GND), U2.EXP@15 (GND), U2.EXP@16 (GND), U3.2 (GND), U3.5 (GND), U3.6 (GND), U4.13 (MTDO), U4.EXP@1 (GND), U4.EXP@2 (GND), U4.EXP@3 (GND), U4.EXP@5 (GND), U4.EXP@6 (GND), U4.EXP@7 (GND), U4.EXP@9 (GND), U4.EXP@10 (GND), U4.EXP@11 (GND), U5.4 (GND), U6.4 (GNDA), U6.6 (GNDIO), U6.12 (SDO2), U6.17 (SDO1), U6.20 (CSB3), U7.2 (VSS), U8.2 (GND), U8.4 (GND), U9.1 (GND), U$1.GND, U$2.GND, Y1.2, Y1.4, Y2.2, Y2.4, Y4.2, Y4.4
LED_B: R10.1, U1.56 (PB4)
LED_G: R9.1, U1.57 (PB5)
LED_R: R8.1, U1.26 (PB0)
unnamed: C2.2, U1.5 (OSC_IN), Y1.1
unnamed: C3.2, U1.6 (OSC_OUT), Y1.3
unnamed: C13.1, U2.32 (P2_4/OSC32K_Q1), Y3.1
unnamed: LED.1 (KRED), R8.2
unnamed: C8.1, U1.31 (VCAP1)
unnamed: C9.1, U1.47 (VCAP2)
unnamed: LED.2 (KGREEN), R9.2
unnamed: LED.3 (KBLUE), R10.2
unnamed: C1.1, L1.1, U1.13 (VDDA)
unnamed: R5.1, U4.31 (RES12K)
unnamed: C21.1, U4.27 (XTAL_OUT), Y4.1
unnamed: U2.26 (RF_N), U3.3 (BAL)
unnamed: R2.2, U2.30 (RBIAS)
unnamed: C12.1, U2.40 (DCOUPL)
unnamed: U2.25 (RF_P), U3.4 (BAL)
unnamed: R3.2, U2.34 (P2_2/DC)
unnamed: C20.1, U4.28 (XTAL_IN), Y4.3
unnamed: R20.2, U7.5 (PROG)
unnamed: C10.2, U2.22 (XOSC_Q1), Y2.1
unnamed: C11.2, U2.23 (XOSC_Q2), Y2.3
unnamed: R4.2, U2.35 (P2_1/DD)
unnamed: R1.1, U2.20 (RESET_N)
unnamed: C19.2, U4.2 (LNA)
unnamed: C14.1, U2.33 (P2_3/OSC32K_Q2), Y3.2
unnamed: ON.A, R11.1
unnamed: Q1.1 (G), R16.1, R17.2
unnamed: Q2.3 (D), R13.1, R14.1
unnamed: Q3.1 (G), R21.2, R22.1
NRST: C28.1, Q2.1 (G), R12.1, RESET/BOOT.1, SWD.2, U1.7 (NRST)
SCL: R6.1, U1.29 (PB10), U6.9 (SCX)
SDA: R7.1, U1.30 (PB11), U6.11 (SDX)
SD_CLK: U4.21 (SD_CLK), U5.6 (SCK)
SD_CMD: U4.20 (SD_CMD), U5.1 (CS)
SD_D0: U4.22 (SD_DATA_0), U5.2 (MISO)
SD_D1: U4.23 (SD_DATA_1), U5.5 (MOSI)
SD_D2: U4.18 (SD_DATA_2), U5.7 (HOLD)
SD_D3: U4.19 (SD_DATA_3), U5.3 (WP)
SW1: R15.2, U1.2 (PC13), USER.2
SWCLK: SWD.4, U1.49 (PA14)
SWDIO: SWD.3, U1.46 (PA13)
USB_DM: J1.2 (D-), U1.44 (PA11)
USB_DP: J1.3 (D+), U1.45 (PA12)
V+: C30.1, EXT-2.2, J2.+, Q3.3 (D), R18.2, U7.3 (VBAT)
VBUS: J1.1 (VBUS), Q1.3 (D), U1.42 (PA9)
VDD_RTC: U4.5 (VDD_RTC)
VIN_3V3: D1.C, Q3.2 (S), U8.1 (VIN)
VPP: C33.+, EXT-1.2, R16.2, U9.3 (VIN)
WIFI_ANT: C19.1, U$1.ANT
WIFI_MODE: U1.34 (PB13), U4.15 (GPIO0)
WIFI_PWD: U1.33 (PB12), U4.7 (CHIP_EN)
WIFI_RST: U1.3 (PC14), U4.32 (EXT_RSTB)
WIFI_RX: U1.15 (PA1), U4.26 (U0TXD)
WIFI_TX: U1.14 (PA0-WKUP), U4.25 (U0RXD)

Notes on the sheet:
TON V1.2 - Microcontroller
TON V1.2 - Bluetooth Low Energy
TON V1.2 - Wi-Fi
TON V1.2 - IMU e Peripherals
TON V1.2 - USB e Regulators
TON Board V1.2 by IOTON Technology. Licensed under CERN OHL v.1.2. http://ohwr.org/cernohl
Original drawing Ton Board by IOTON Technology
k006b
*Pins 20 and 21 are not 5V tolerant!
Fast: RESET Slow (>1s): BOOT

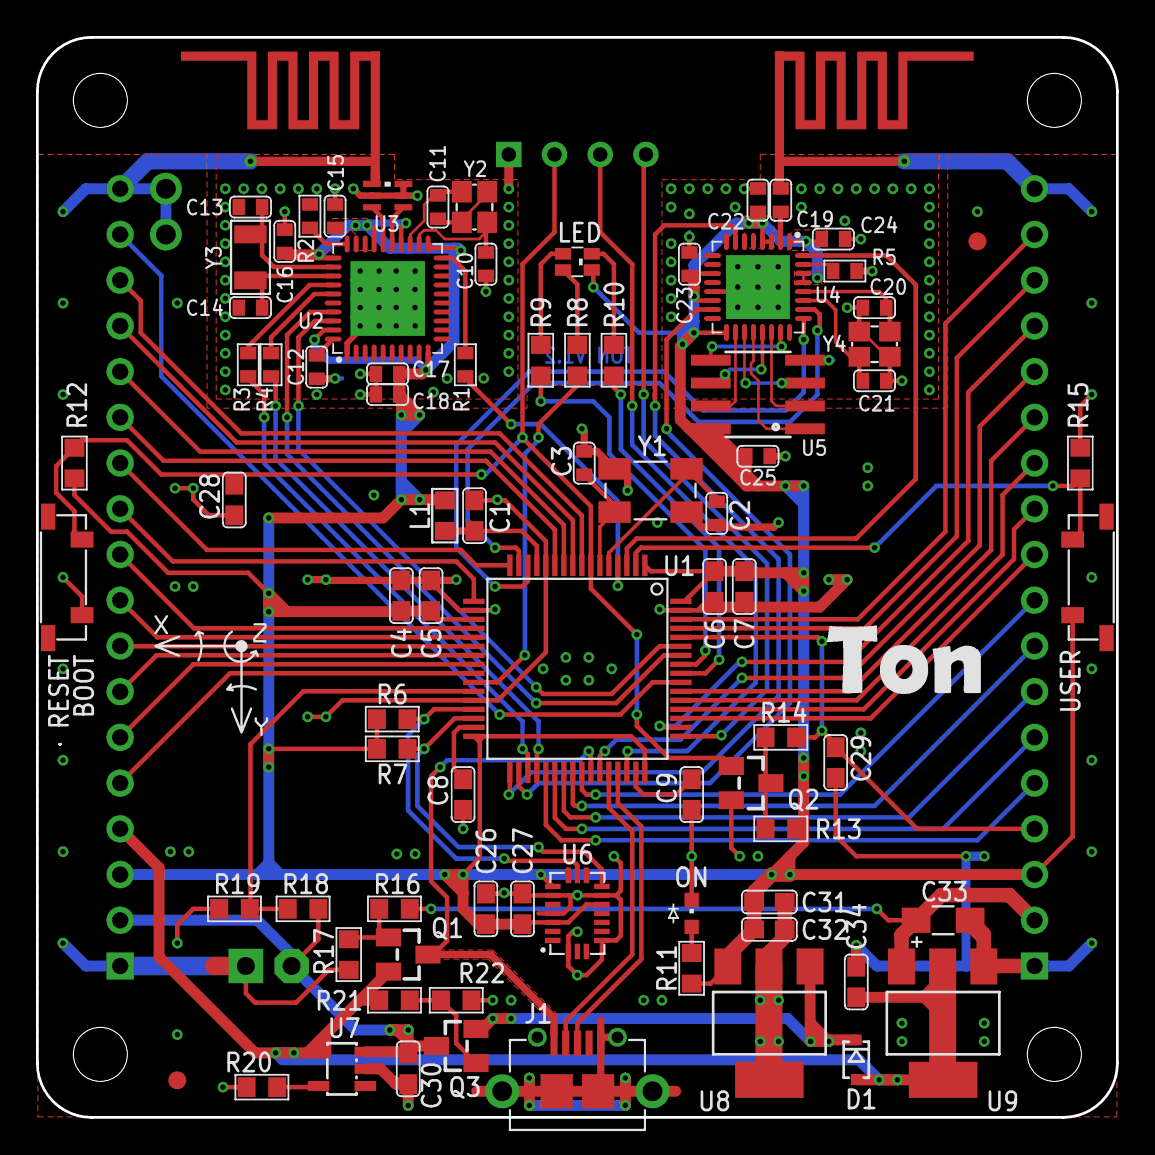
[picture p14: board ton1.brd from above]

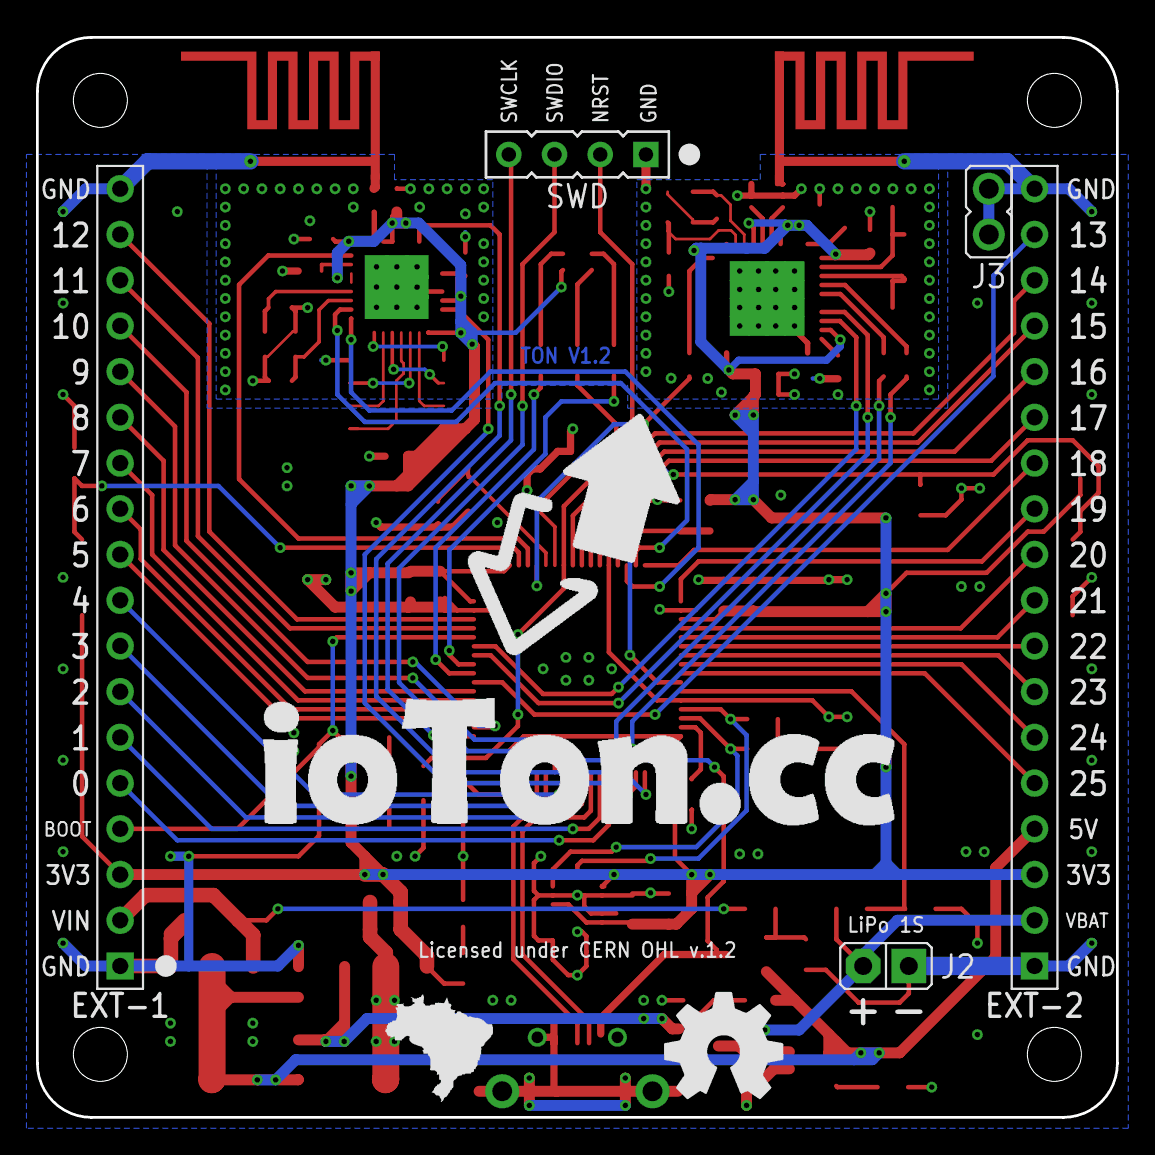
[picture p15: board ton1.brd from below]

Board: 2 copper layers, 60.0 x 60.0 mm, 88 parts (5 on the bottom side), 92 nets.

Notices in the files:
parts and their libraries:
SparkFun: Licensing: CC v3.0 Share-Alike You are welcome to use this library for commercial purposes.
